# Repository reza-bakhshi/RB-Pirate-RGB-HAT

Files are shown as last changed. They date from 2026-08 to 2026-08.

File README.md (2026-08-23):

<div align="center">

# RB-Pirate RGB & Button HAT

**Optional RGB lighting and physical-button expansion for RB-Pirate**






</div>

RB-Pirate RGB & Button HAT adds programmable RGB visual feedback and a physical
user button to the [RB-Pirate](https://github.com/reza-bakhshi/RB-Pirate)
hardware debugging tool. It enables status lighting, animations, button-based
mode control, and scriptable user input through the RB-Pirate firmware.

The HAT is completely optional. RB-Pirate remains fully functional without it,
so the expansion can be installed only when visual feedback or a physical
button is useful.

## PCB gallery

<table>
  <tr>
    <th width="50%">Top</th>
    <th width="50%">Bottom</th>
  </tr>
  <tr>
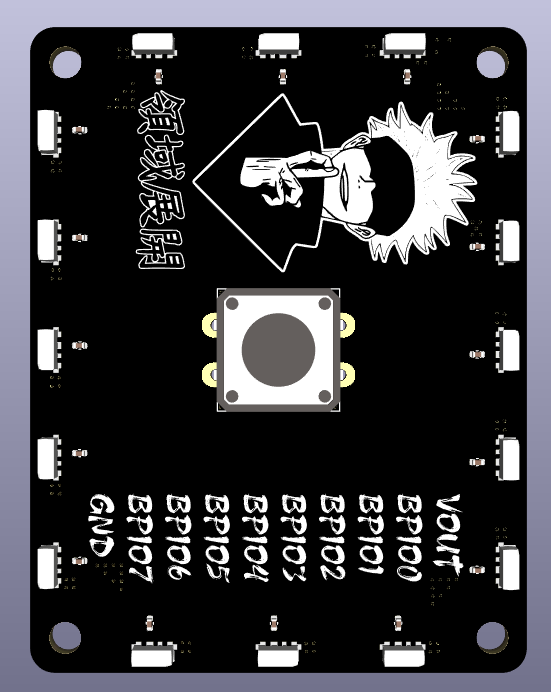
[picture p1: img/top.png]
Top side of the RB-Pirate RGB and Button HAT
    <td></td>
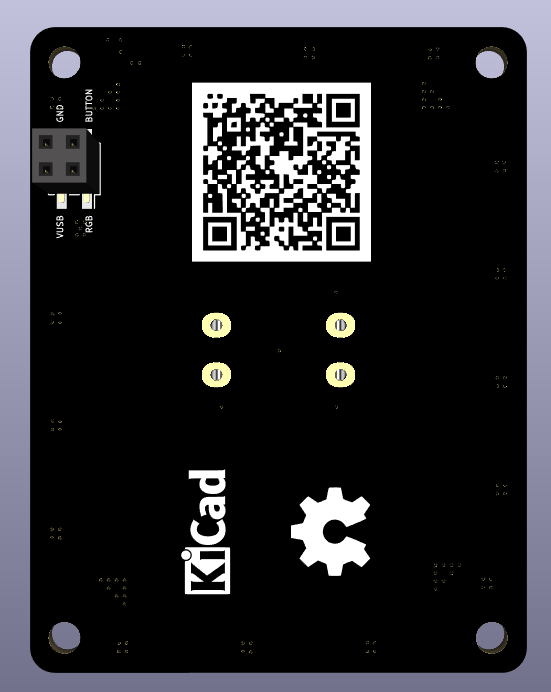
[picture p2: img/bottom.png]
Bottom side of the RB-Pirate RGB and Button HAT
    <td></td>
  </tr>
</table>

## Hardware features

- 16 individually addressable SK6812 RGB LEDs arranged around the board
- Side-facing LEDs for perimeter lighting and visual effects
- One 100 nF local decoupling capacitor for each RGB LED
- Large central momentary push button
- Dedicated RGB data and button signals
- Compact four-pin, 2.54 mm SMD connection to RB-Pirate
- Four mounting holes for mechanical alignment
- Two-layer, 1.6 mm PCB
- KiCad 10 schematic and PCB design files

## Firmware features

When used with the
[custom RB-Pirate firmware](https://github.com/reza-bakhshi/RB-Pirate-Firmware),
the HAT provides:

- RGB status indication
- Startup and activity animations
- Introduction and party-mode effects
- Physical escape and mode-control input
- Scriptable button input for automation and custom workflows

## Connector pinout

The HAT connects to RB-Pirate through connector **J1**.

| Pin | Signal | Description |
|:---:|---|---|
| 1 | RGB_IN | Serial data input for the SK6812 LED chain |
| 2 | BUTTON | User-button signal to RB-Pirate |
| 3 | VDD / VUSB | Power input for the HAT |
| 4 | GND | Ground |

> [!NOTE]
> Power off RB-Pirate before installing or removing the HAT. Check connector
> orientation and pin alignment before applying power.

## Related projects

- [RB-Pirate hardware](https://github.com/reza-bakhshi/RB-Pirate)
- [RB-Pirate firmware](https://github.com/reza-bakhshi/RB-Pirate-Firmware)

## License

This project is released under the [MIT License](LICENSE).

Third-party symbols, footprints, models, and other bundled resources remain
subject to their respective licenses.

---

<div align="center">
  <sub>Optional light and button control for the RB-Pirate ecosystem.</sub>
</div>

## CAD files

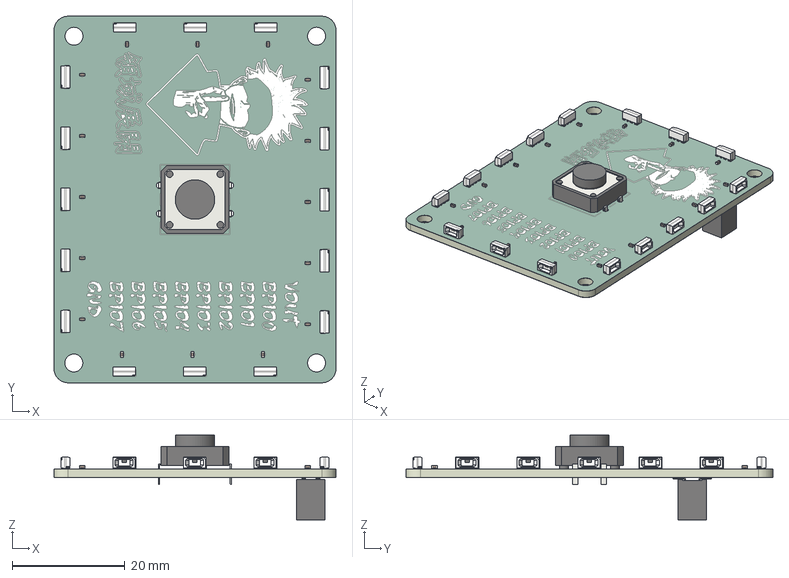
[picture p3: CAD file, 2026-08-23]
RB-Pirate-RGB-HAT.step
50.0 x 65.0 x 15.1 mm
sk6812side v0 x 16
C_0402_1005Metric x 16
PinSocket_2x02_P2.54mm_Vertical_SMD
RB-Pirate-RGB-HAT_silkscreen x 2
RB-Pirate-RGB-HAT_soldermask x 2
RB-Pirate-RGB-HAT_PCB

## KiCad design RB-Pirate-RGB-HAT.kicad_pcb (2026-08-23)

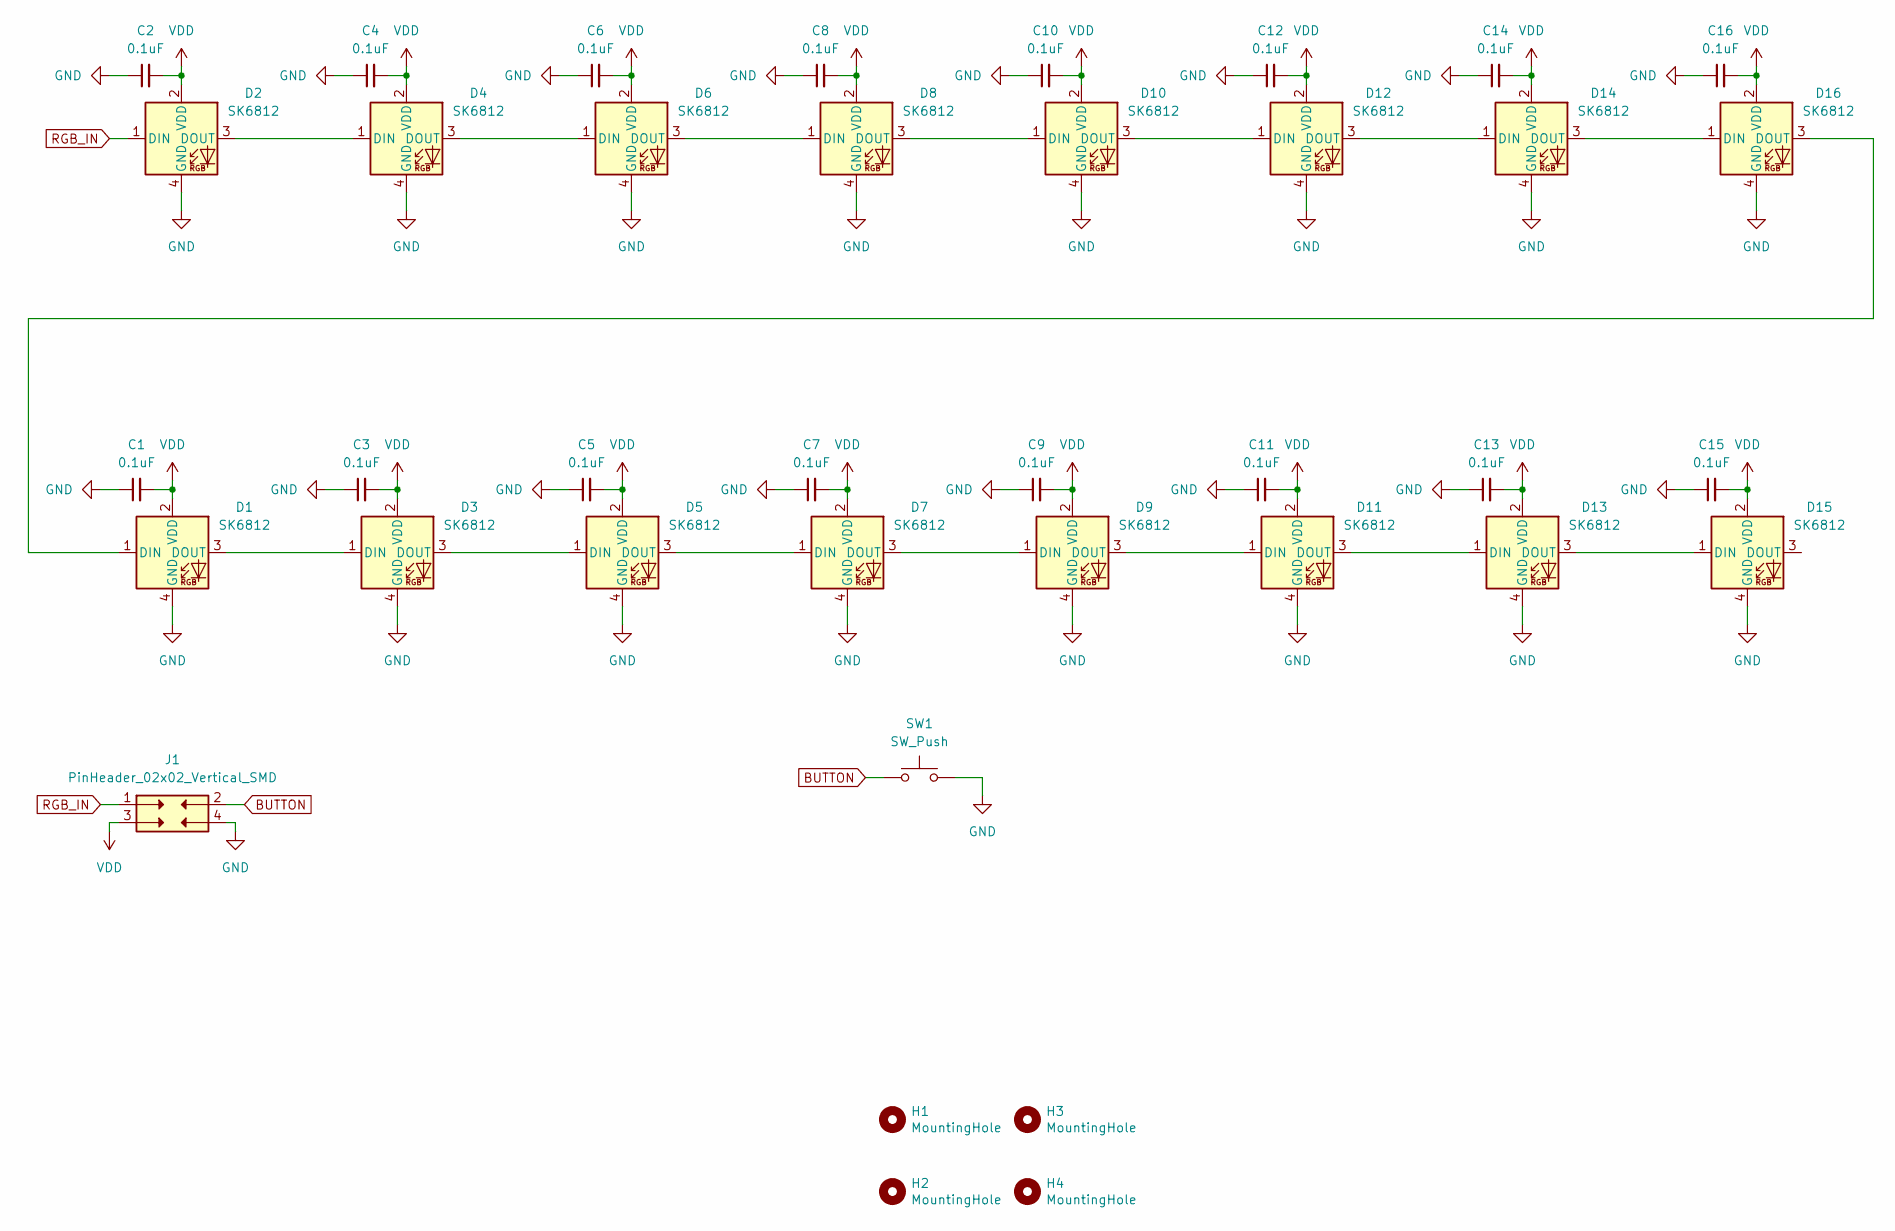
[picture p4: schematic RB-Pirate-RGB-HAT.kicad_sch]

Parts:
C1, C2, C3, C4, C5, C6, C7, C8, C9, C10, C11, C12, C13, C14, C15, C16: 0.1uF; C_0402_1005Metric; Voltage 16V; Tolerance 10%
D1, D2, D3, D4, D5, D6, D7, D8, D9, D10, D11, D12, D13, D14, D15, D16: SK6812; SK6812-side-a
H1, H2, H3, H4: MountingHole; MountingHole_3.2mm_M3
J1: PinHeader_02x02_Vertical_SMD; PinSocket_2x02_P2.54mm_Vertical_SMD
SW1: SW_Push; Push_Button_W12mm

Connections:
BUTTON: J1.2, SW1.1
GND: C1.1, C2.1, C3.1, C4.1, C5.1, C6.1, C7.1, C8.1, C9.1, C10.1, C11.1, C12.1, C13.1, C14.1, C15.1, C16.1, D1.4 (GND), D2.4 (GND), D3.4 (GND), D4.4 (GND), D5.4 (GND), D6.4 (GND), D7.4 (GND), D8.4 (GND), D9.4 (GND), D10.4 (GND), D11.4 (GND), D12.4 (GND), D13.4 (GND), D14.4 (GND), D15.4 (GND), D16.4 (GND), J1.4, SW1.2
unnamed: D1.1 (DIN), D16.3 (DOUT)
unnamed: D1.3 (DOUT), D3.1 (DIN)
unnamed: D2.3 (DOUT), D4.1 (DIN)
unnamed: D3.3 (DOUT), D5.1 (DIN)
unnamed: D4.3 (DOUT), D6.1 (DIN)
unnamed: D5.3 (DOUT), D7.1 (DIN)
unnamed: D6.3 (DOUT), D8.1 (DIN)
unnamed: D7.3 (DOUT), D9.1 (DIN)
unnamed: D8.3 (DOUT), D10.1 (DIN)
unnamed: D10.3 (DOUT), D12.1 (DIN)
unnamed: D9.3 (DOUT), D11.1 (DIN)
unnamed: D11.3 (DOUT), D13.1 (DIN)
unnamed: D12.3 (DOUT), D14.1 (DIN)
unnamed: D13.3 (DOUT), D15.1 (DIN)
unnamed: D14.3 (DOUT), D16.1 (DIN)
RGB_IN: D2.1 (DIN), J1.1
VDD: C1.2, C2.2, C3.2, C4.2, C5.2, C6.2, C7.2, C8.2, C9.2, C10.2, C11.2, C12.2, C13.2, C14.2, C15.2, C16.2, D1.2 (VDD), D2.2 (VDD), D3.2 (VDD), D4.2 (VDD), D5.2 (VDD), D6.2 (VDD), D7.2 (VDD), D8.2 (VDD), D9.2 (VDD), D10.2 (VDD), D11.2 (VDD), D12.2 (VDD), D13.2 (VDD), D14.2 (VDD), D15.2 (VDD), D16.2 (VDD), J1.3

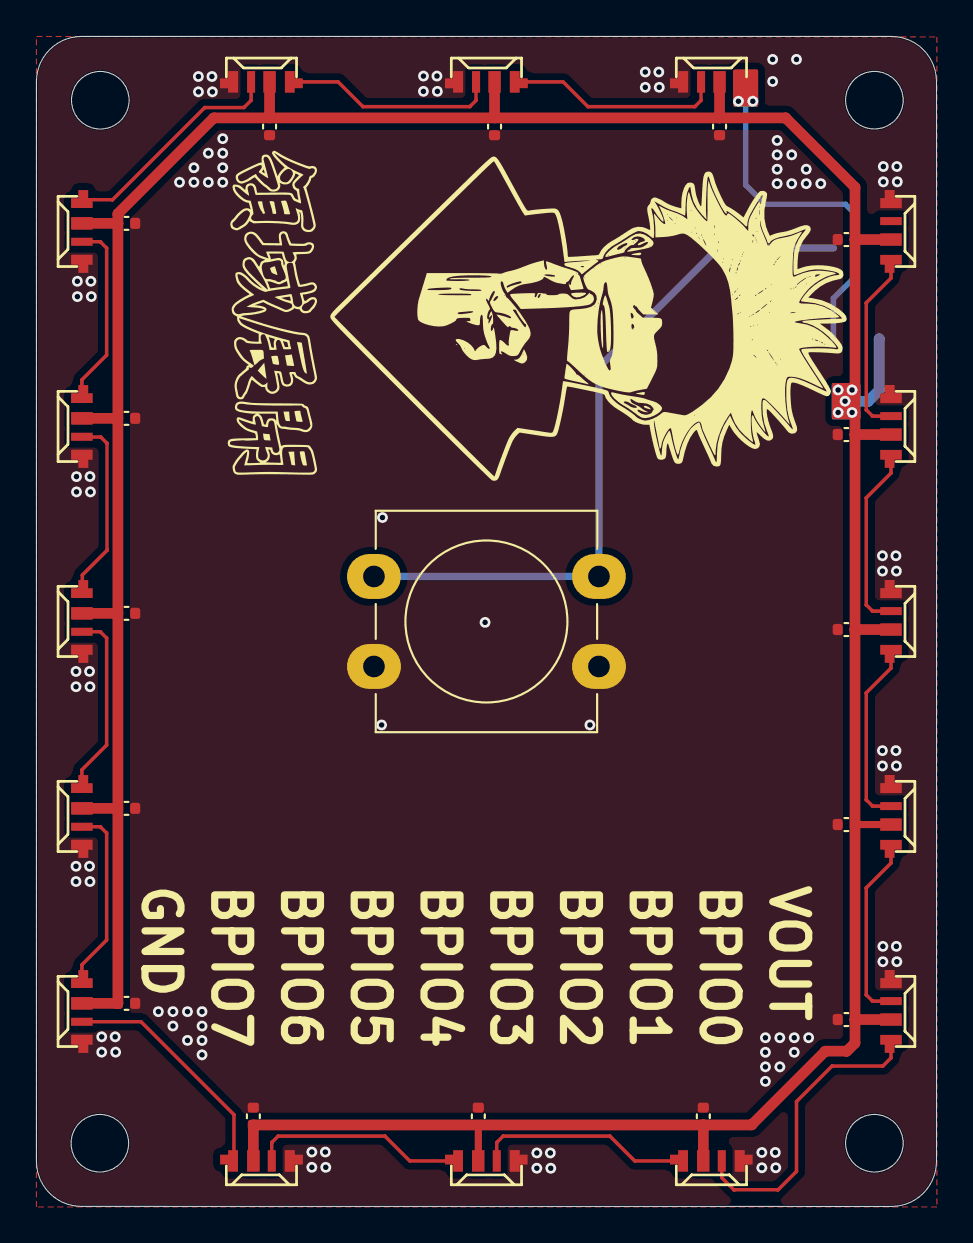
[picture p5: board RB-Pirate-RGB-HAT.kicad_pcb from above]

Board: 2 copper layers, 50.0 x 65.0 mm, 38 parts (1 on the bottom side), 19 nets.

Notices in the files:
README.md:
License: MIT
